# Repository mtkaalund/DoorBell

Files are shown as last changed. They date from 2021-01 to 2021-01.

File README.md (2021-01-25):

# DoorBell
Perhaps an over-engineered doorbell using a Arduino Pro Mini and a DFPlayer Mini.

## Hardware
The schematic are done in KiCad 5. 
A little story, at first I only meant to put a electrial schematic together, so it was easier to create a breadboard for this project.

But as I thought it would be a good pratics to create a pcb of it (mostly because it has been a long time since I did one).

As I was working with creating the schematics and the pcb, I tought it was underused, as it did'nt use all or expose the pins on the arduino or the DFPlayer Mini.
So I exposed them to the world and now it became a semi development board for the Arduino Pro Mini and DFPlayer Mini.

There are two headers "Arduino IO" and "DFPlayer IO" which expose the remaining IO's.

### DFPlayer IO
 Header Pin | DFPlayer Pin
------------|--------------
1 | DF Adkey 2
2 | DF Adkey 1
3 | DF IO 2
4 | DF IO 1
5 | DF DAC L
6 | DF DAC R

### Arduino IO
Header Pin | Arduino Pin 
-----------|-------------
1 | GND  
2 | VCC 
3 | A3   
4 | A2  
5 | A1  
6 | 13 ( SCK ) 
7 | 12 ( MISO )
8 | 9 ( Low battery LED )
9 | 8
10 | Reset
11 | 0 ( Rx )
12 | 1 ( Tx )
13 | GND
14 | VCC

### Libs
[Kicad footprints](https://github.com/joeylevy/KiCad_Arduino_Nano_DFPlayer_footprints)
[Kicad schematic symbols](https://github.com/RoboUlbricht/kicad.lib)

### Schematic
Can be found in the [hardware](https://github.com/mtkaalund/DoorBell/tree/main/hardware/DoorBell) folder as
either [Kicad Schematic](https://github.com/mtkaalund/DoorBell/blob/main/hardware/DoorBell/DoorBell.sch) or as a [PDF](https://github.com/mtkaalund/DoorBell/blob/main/hardware/DoorBell/DoorBell.pdf).

The pcb layout I have done can also be found as [Kicad PCB](https://github.com/mtkaalund/DoorBell/blob/main/hardware/DoorBell/DoorBell.kicad_pcb) or as pdf's [B_cu.pdf](https://github.com/mtkaalund/DoorBell/blob/main/hardware/DoorBell/DoorBell-B_Cu.pdf) [F_cu.pdf](https://github.com/mtkaalund/DoorBell/blob/main/hardware/DoorBell/DoorBell-F_Cu.pdf) [F_SilkS.pdf](https://github.com/mtkaalund/DoorBell/blob/main/hardware/DoorBell/DoorBell-F_SilkS.pdf)

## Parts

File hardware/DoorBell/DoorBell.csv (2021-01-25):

Id | Designator | Package | Quantity | Designation | Supplier and ref
1 | REF** | WEEE-Logo_4.2x6mm_SilkScreen | 1 | WEEE-Logo_4.2x6mm_SilkScreen
2 | REF** | OSHW-Logo2_7.3x6mm_SilkScreen | 1 | OSHW-Logo2_7.3x6mm_SilkScreen
3 | REF** | KiCad-Logo2_8mm_SilkScreen | 1 | KiCad-Logo2_8mm_SilkScreen
4 | P1 | Socket_Strip_Arduino_1x12 | 1 | Digital
5 | P2 | Socket_Strip_Arduino_1x06 | 1 | COM
6 | P3,P5 | Socket_Strip_Arduino_1x02 | 2 | ADC
7 | P4 | Socket_Strip_Arduino_1x12 | 1 | Analog
8 | C1 | C_Rect_L7.0mm_W2.5mm_P5.00mm | 1 | 100n
9 | D1 | D_DO-35_SOD27_P7.62mm_Horizontal | 1 | 1N4148
10 | D2 | LED_D3.0mm | 1 | LED
11 | J1 | BarrelJack_Horizontal | 1 | Barrel_Jack_Switch_Pin3Ring
12 | J2 | USB_A_CONNFLY_DS1095-WNR0 | 1 | USB_A
13 | J3 | PinHeader_1x02_P2.54mm_Vertical | 1 | Speaker
14 | J4 | PinHeader_1x14_P2.54mm_Vertical | 1 | ARDUINO_IO
15 | J5 | PinHeader_1x06_P2.54mm_Vertical | 1 | DFPlayerIO
16 | R1,R2,R3,R4,R5,R6,R9 | R_Axial_DIN0204_L3.6mm_D1.6mm_P7.62mm_Horizontal | 7 | 1K
17 | R7 | R_Axial_DIN0204_L3.6mm_D1.6mm_P7.62mm_Horizontal | 1 | 10K
18 | R8 | R_Axial_DIN0204_L3.6mm_D1.6mm_P7.62mm_Horizontal | 1 | 7K
19 | R10 | R_Axial_DIN0204_L3.6mm_D1.6mm_P7.62mm_Horizontal | 1 | 100
20 | SW1 | TerminalBlock_RND_205-00001_1x02_P5.00mm_Horizontal | 1 | DoorBell
21 | SW2 | TerminalBlock_RND_205-00001_1x02_P5.00mm_Horizontal | 1 | Volume Up
22 | SW3 | TerminalBlock_RND_205-00001_1x02_P5.00mm_Horizontal | 1 | Volume Down
23 | SW4 | TerminalBlock_RND_205-00001_1x02_P5.00mm_Horizontal | 1 | Select
24 | SW5 | TerminalBlock_RND_205-00001_1x02_P5.00mm_Horizontal | 1 | Next
25 | SW6 | TerminalBlock_RND_205-00001_1x02_P5.00mm_Horizontal | 1 | Prev
26 | U1 | DFPlayer_V2 | 1 | DFPLAYER_MINI
27 | H1,H2,H3,H4 | MountingHole_5.5mm_Pad_Via | 4 | MountingHole_Pad
28 | D3 | LED_D3.0mm | 1 | LowBatteryLED
29 | R11 | R_Axial_DIN0204_L3.6mm_D1.6mm_P7.62mm_Horizontal | 1 | 220

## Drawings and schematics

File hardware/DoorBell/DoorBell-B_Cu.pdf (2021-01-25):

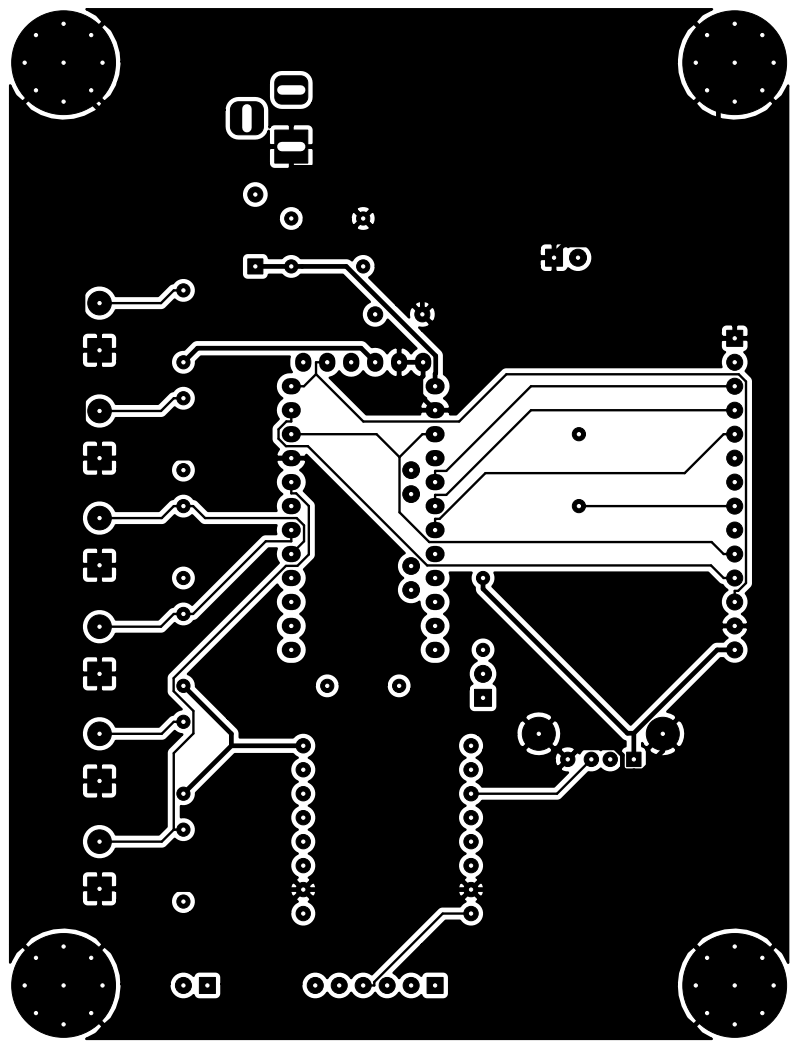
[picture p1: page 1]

File: DoorBell.kicad_pcb Sheet: mtkaalund.dk

Id: 1/1 Title: DoorBell Developmentboard

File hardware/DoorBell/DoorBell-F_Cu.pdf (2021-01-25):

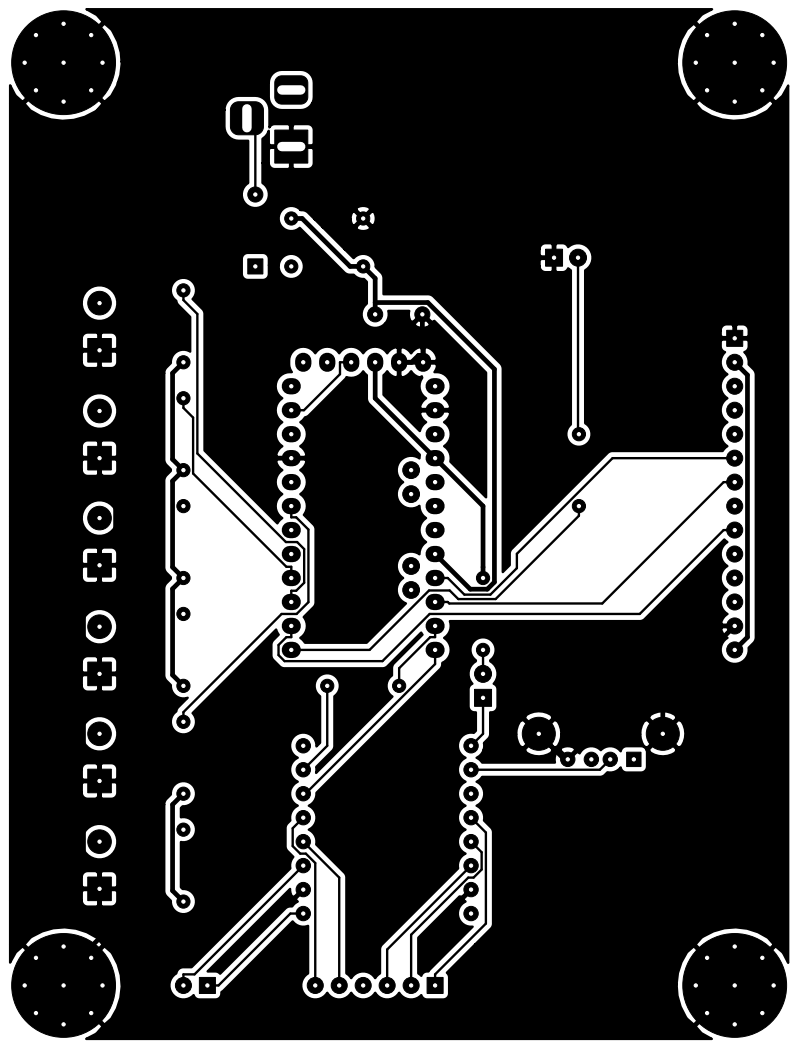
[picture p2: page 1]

File: DoorBell.kicad_pcb Sheet: mtkaalund.dk

Id: 1/1 Title: DoorBell Developmentboard

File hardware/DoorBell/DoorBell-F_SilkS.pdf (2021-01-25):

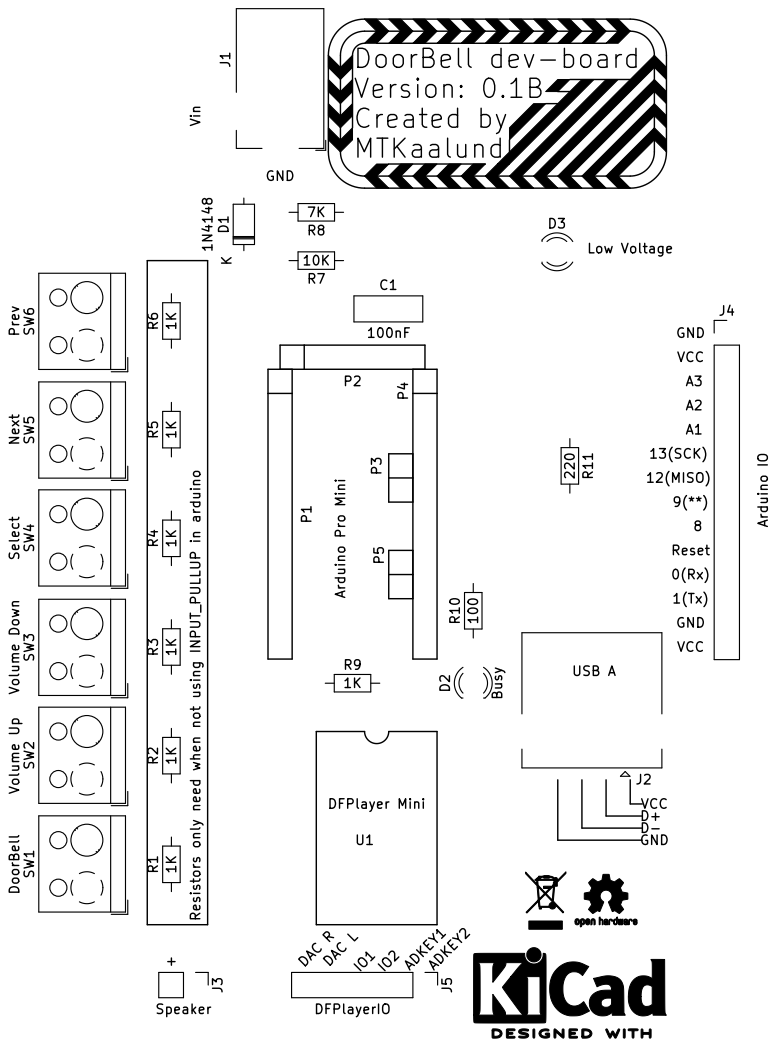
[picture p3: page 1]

File: DoorBell.kicad_pcb Sheet: mtkaalund.dk DoorBell dev-board
Version: 0.1B
Created by

Id: 1/1 Title: DoorBell Developmentboard

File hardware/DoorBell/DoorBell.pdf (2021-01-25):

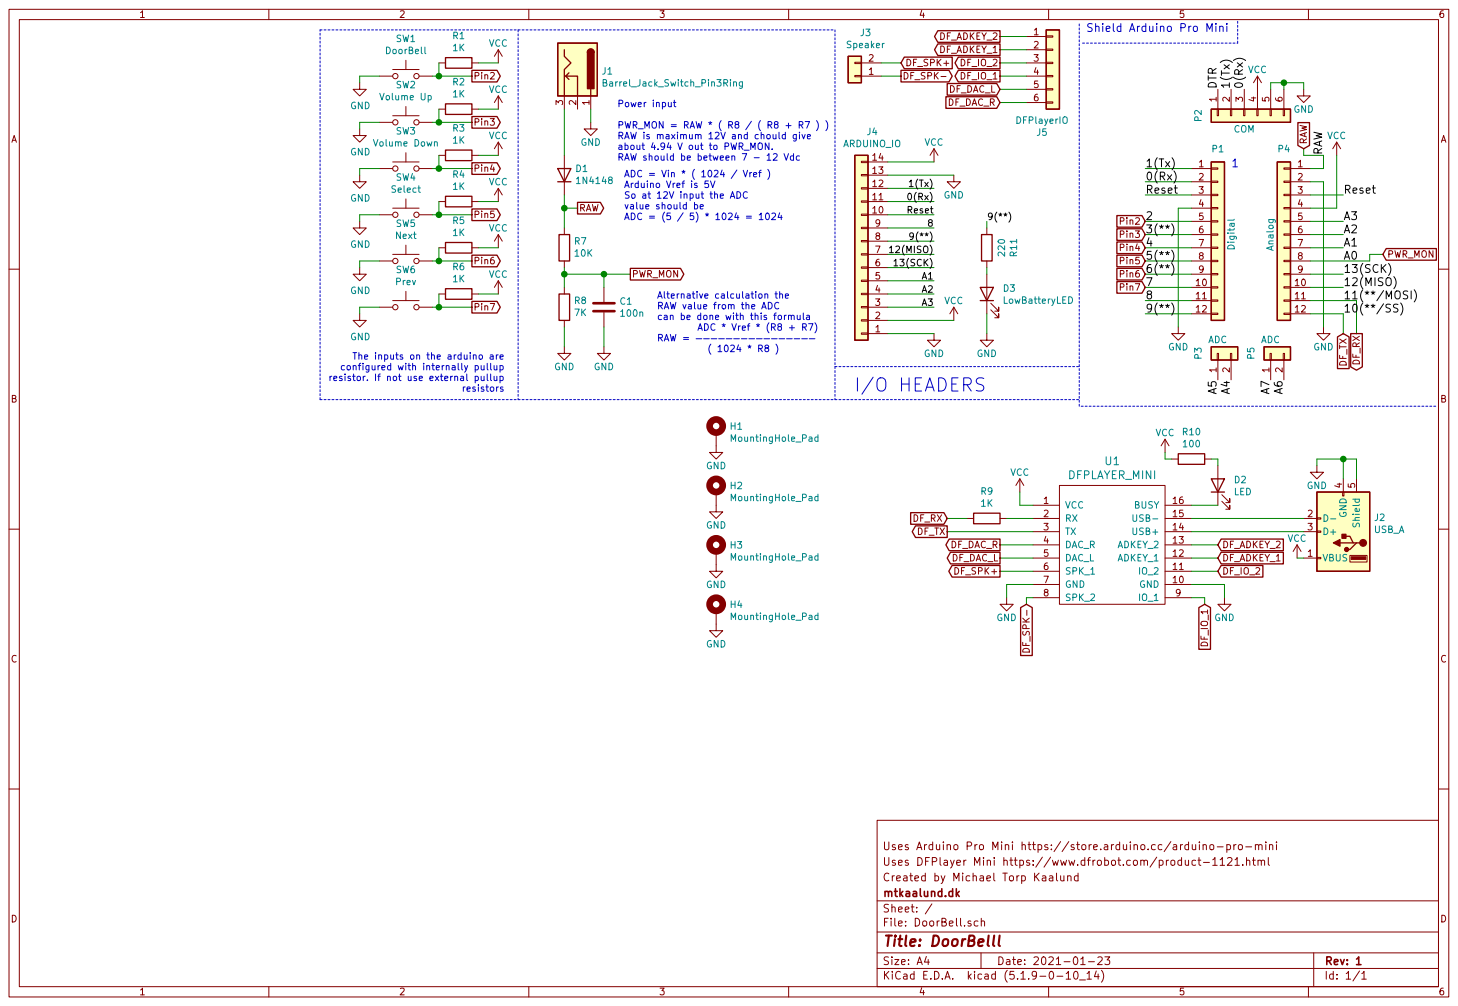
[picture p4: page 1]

1K GND GND GND GND

RAW is maximum 12V and chould give about 4.94 V out to PWR_MON. RAW should be between 7 - 12 Vdc The inputs on the arduino are

ADC = Vin * ( 1024 / Vref ) Arduino Vref is 5V

So at 12V input the ADC value should be ADC = (5 / 5) * 1024 = 1024

LowBatteryLED 220 R11 GND GND GND GND

can be done with this formula
ADC * Vref * (R8 + R7) RAW =

Uses Arduino Pro Mini https://store.arduino.cc/arduino-pro-mini GND
I/O HEADERS

configured with internally pullup
resistor. If not use external pullup

Uses DFPlayer Mini https://www.dfrobot.com/product-1121.html
Id: 1/1 Title: DoorBelll File: DoorBell.sch Sheet: / mtkaalund.dk Created by Michael Torp Kaalund

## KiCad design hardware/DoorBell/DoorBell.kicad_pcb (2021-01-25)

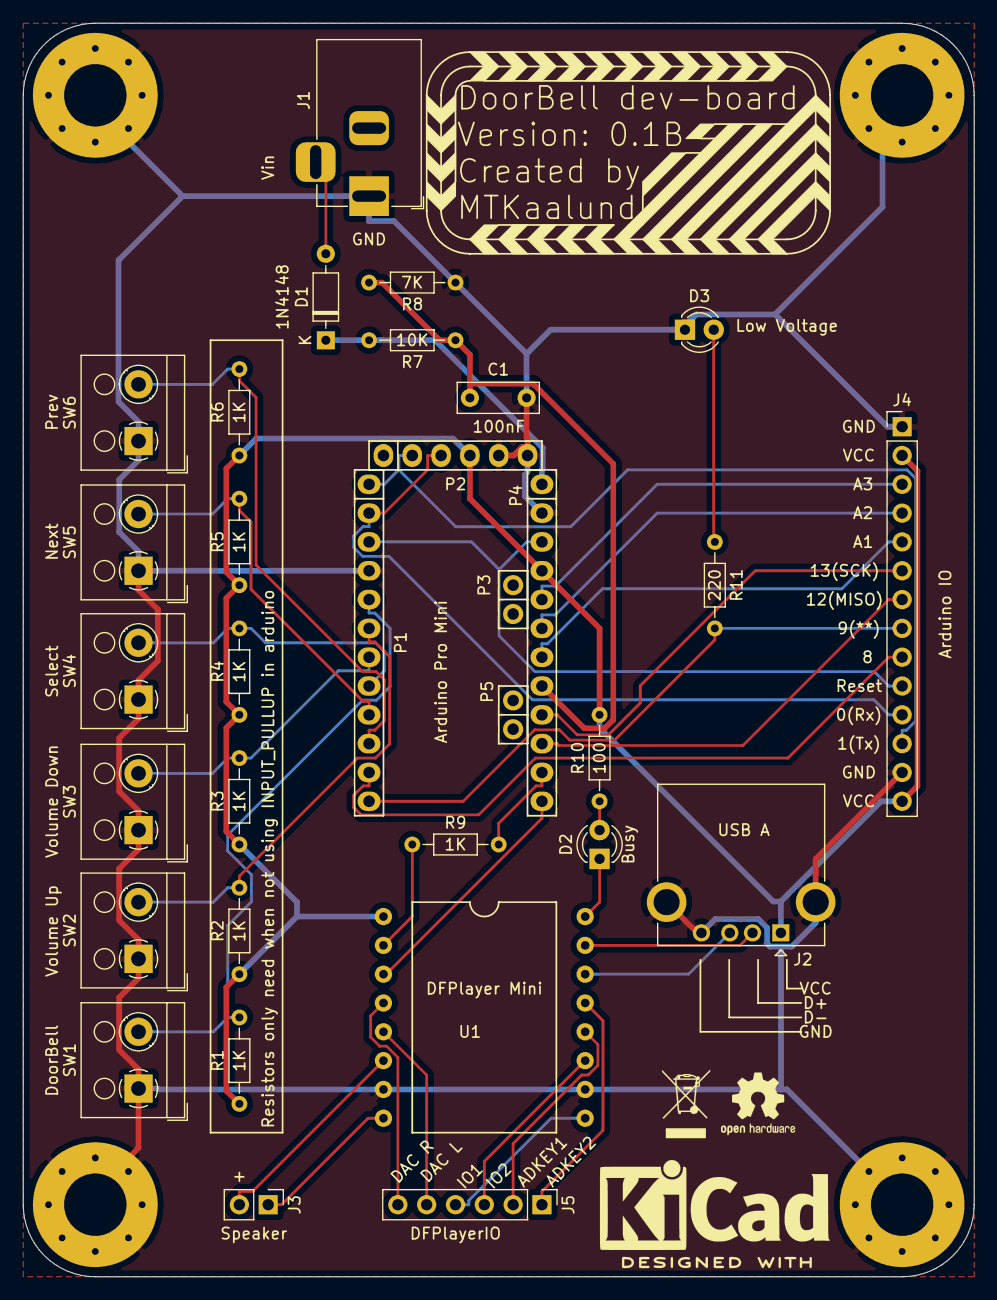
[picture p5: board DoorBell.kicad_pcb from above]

Board: 2 copper layers, 83.8 x 110.5 mm, 39 parts (0 on the bottom side), 37 nets.

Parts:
C1: 100n; C_Rect_L7.0mm_W2.5mm_P5.00mm
D1: 1N4148; D_DO-35_SOD27_P7.62mm_Horizontal
D2: LED; LED_D3.0mm
D3: LowBatteryLED; LED_D3.0mm
H1, H2, H3, H4: MountingHole_Pad; MountingHole_5.5mm_Pad_Via
J1: Barrel_Jack_Switch_Pin3Ring; BarrelJack_Horizontal
J2: USB_A; USB_A_CONNFLY_DS1095-WNR0
J3: Speaker; PinHeader_1x02_P2.54mm_Vertical
J4: ARDUINO_IO; PinHeader_1x14_P2.54mm_Vertical
J5: DFPlayerIO; PinHeader_1x06_P2.54mm_Vertical
LOGO1: KiCad-Logo2_8mm_SilkScreen
LOGO2: WEEE-Logo_4.2x6mm_SilkScreen
LOGO3: OSHW-Logo2_7.3x6mm_SilkScreen
P1: Digital; Socket_Strip_Arduino_1x12
P2: COM; Socket_Strip_Arduino_1x06
P3, P5: ADC; Socket_Strip_Arduino_1x02
P4: Analog; Socket_Strip_Arduino_1x12
R1, R2, R3, R4, R5, R6, R9: 1K; R_Axial_DIN0204_L3.6mm_D1.6mm_P7.62mm_Horizontal
R7: 10K; R_Axial_DIN0204_L3.6mm_D1.6mm_P7.62mm_Horizontal
R8: 7K; R_Axial_DIN0204_L3.6mm_D1.6mm_P7.62mm_Horizontal
R10: 100; R_Axial_DIN0204_L3.6mm_D1.6mm_P7.62mm_Horizontal
R11: 220; R_Axial_DIN0204_L3.6mm_D1.6mm_P7.62mm_Horizontal
SW1: DoorBell; TerminalBlock_RND_205-00001_1x02_P5.00mm_Horizontal
SW2: Volume Up; TerminalBlock_RND_205-00001_1x02_P5.00mm_Horizontal
SW3: Volume Down; TerminalBlock_RND_205-00001_1x02_P5.00mm_Horizontal
SW4: Select; TerminalBlock_RND_205-00001_1x02_P5.00mm_Horizontal
SW5: Next; TerminalBlock_RND_205-00001_1x02_P5.00mm_Horizontal
SW6: Prev; TerminalBlock_RND_205-00001_1x02_P5.00mm_Horizontal
U1: DFPLAYER_MINI; DFPlayer_V2

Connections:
/0(Rx): J4.11, P1.2, P2.3
/1(Tx): J4.12, P1.1, P2.2
/8: J4.9, P1.11
/9(**): J4.8, P1.12, R11.2
/12(MISO): J4.7, P4.10
/13(SCK): J4.6, P4.9
/A1: J4.5, P4.7
/A2: J4.4, P4.6
/A3: J4.3, P4.5
/Reset: J4.10, P1.3, P4.3
DF_ADKEY_1: J5.2, U1.12
DF_ADKEY_2: J5.1, U1.13
DF_DAC_L: J5.5, U1.5
DF_DAC_R: J5.6, U1.4
DF_IO_1: J5.4, U1.9
DF_IO_2: J5.3, U1.11
DF_RX: P4.11, R9.2
DF_SPK+: J3.2, U1.6
DF_SPK-: J3.1, U1.8
DF_TX: P4.12, U1.3
GND: C1.2, D3.1, H1.1, H2.1, H3.1, H4.1, J1.1, J2.4, J2.5, J4.1, J4.13, P1.4, P2.5, P2.6, P4.2, R8.1, SW1.1, SW2.1, SW3.1, SW4.1, SW5.1, SW6.1, U1.7, U1.10
unnamed: D1.2, J1.3
unnamed: D2.1, U1.16
unnamed: D2.2, R10.1
unnamed: D3.2, R11.1
unnamed: J2.2, U1.15
unnamed: J2.3, U1.14
unnamed: R9.1, U1.2
PWR_MON: C1.1, P4.8, R7.1, R8.2
Pin2: P1.5, R1.2, SW1.2
Pin3: P1.6, R2.2, SW2.2
Pin4: P1.7, R3.2, SW3.2
Pin5: P1.8, R4.2, SW4.2
Pin6: P1.9, R5.2, SW5.2
Pin7: P1.10, R6.2, SW6.2
RAW: D1.1, P4.1, R7.2
VCC: J2.1, J4.2, J4.14, P2.4, P4.4, R1.1, R2.1, R3.1, R4.1, R5.1, R6.1, R10.2, U1.1

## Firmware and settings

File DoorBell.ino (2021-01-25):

// Author: Michael Torp Kaalund 
// File: DoorBell.ino
// Description:
//  An over engineered doorbell solution using the DFPlayerMini board.
//  It has following buttons connected to the arduino pro mini as follows:
//    Doorbell    - pin 2
//    Volume up   - pin 3
//    Volume down - pin 4
//    Select      - pin 5
//    Next sound  - pin 6
//    Prev sound  - pin 7
// In order to compile you'll need the arduino enviroment and ezButton lib and DFRobotDFPlayerMini lib.
// https://arduinogetstarted.com/library/arduino-multiple-button-all-example
// https://wiki.dfrobot.com/DFPlayer_Mini_SKU_DFR0299

#include <Arduino.h>
#include <EEPROM.h>
#include <SoftwareSerial.h>
#include <DFRobotDFPlayerMini.h>
#include <ezButton.h>

#include "SerialPrintMessages.h"

  // Buttons ( using C++ enum class )
enum class button {
  DOORBELL,
  VOL_PLUS,
  VOL_MINUS,
  SELECT,
  NEXT,
  PREV,
  END
};

ezButton *buttons[ (int) button::END ] = {
  new ezButton(2),
  new ezButton(3),
  new ezButton(4),
  new ezButton(5),
  new ezButton(6),
  new ezButton(7)
};

typedef struct
{
  int saved_number;
  int volume;
} stats;

static stats ee_stats;
const int state_eeprom_address = 0;

static int max_files = 0;

// Our power monitor input pin
const int pwr_mon_pin = A0;
const int low_voltage_pin = 9;
#define VDIV_R8       7000    // Value of R8 in the resistor divider network
#define VDIV_R7      10000    // Value of R7 in the resistor divider network
#define VREF             5    // Arduino reference voltage
#define PWR_IN(x) ( ( (float) (x) * VREF * ( VDIV_R8 + VDIV_R7 ) ) / ( 1024 * VDIV_R8 ) )
#define CALC_ADC(x) ( (x) * 1024 * ((VDIV_R8) / ( VDIV_R8 + VDIV_R7 ) ) / VREF )
#define VOLTAGE_MIN CALC_ADC( 8.3 ) 
const int read_adc_every = 50; // Reading the ADC every 500 ms
const int read_adc_number = 10; // the number of times adc is going to be readed
int adc_reading[ read_adc_number ];
int adc_count = 0;
static int adc_timer = 0;
int adc_total = 0;
int adc_value = 0;
bool low_voltage_is_active = false;
static uint8_t low_voltage_counter = 0;


// Setting for the DFPlayer Mini
SoftwareSerial dfplayer_serial( 10, 11 ); // RX, TX
DFRobotDFPlayerMini cDFPlayer;

void setup() {
  // Read EEPROM
  EEPROM.get( state_eeprom_address, ee_stats );
  
  dfplayer_serial.begin( 9600 );
  Serial.begin( 115200 );

  mtk::PrintWelcome();

  if( ! cDFPlayer.begin( dfplayer_serial ) ) 
  {
    mtk::PrintDFPlayerFailedToInit();
  }
  Serial.println(F("READY!"));

  // Reading the current maks count off files
  max_files = cDFPlayer.readFileCounts();
  // The saved filenumber is bigger that the
  // maximum availeble files. Then set it to the maximum
  if( ee_stats.saved_number > max_files ) 
    ee_stats.saved_number = max_files;

  if( ee_stats.saved_number < 0 )
    ee_stats.saved_number = 0;

  if( ee_stats.volume > 30 )
    ee_stats.volume = 30;

  if( ee_stats.volume < 0 )
    ee_stats.volume = 0;

  cDFPlayer.volume( ee_stats.volume );
  cDFPlayer.disableLoop();
  cDFPlayer.play( ee_stats.saved_number );

  Serial.print("Found : ");
  Serial.print( max_files );
  Serial.println(" files on the sd card");
  Serial.print("Saved number: ");
  Serial.print((int)ee_stats.saved_number);
  Serial.print(" Volume: ");
  Serial.println((int)ee_stats.volume);

  adc_timer = millis();
  // Resets to adc_reading's to 0
  for( int i = 0; i < read_adc_number; i++ )
  {
    adc_reading[ i ] = 0;
  }
}

void loop() {
  // First reading the buttons
  for( int i = 0; i < (int)button::END; i++ )
  {
     buttons[ i ]->loop();
  }

  // We are going to read the adc at an interval atleast read_adc_every
  if( (millis() - adc_timer ) > read_adc_every )
  {
    adc_timer = millis();
    // We are going to smooth out the adc over read_adc_number times. 
    adc_total -= adc_reading[ adc_count ];
    adc_reading[ adc_count ] = analogRead( pwr_mon_pin );
    total += adc_reading[ adc_count ];
    adc_count++;
    // Wrap adc_count around
    if( adc_count >= read_adc_number )
    {
      adc_count = 0;
    }
    // Calculate the average
    adc_value = adc_total / read_adc_number;

    Serial.print( "Power voltage: ");
    Serial.print( PWR_IN( adc_value ) );
    Serial.println(" V");

    // If the read value is equal or lower than VOLTAGE_MIN
    // the set low_voltage_is_active to true
    // and low_voltage_pin to output
    if( adc_value <= VOLTAGE_MIN )
    {
      Serial.println("Low voltage");
      low_voltage_is_active = true;

      pinMode(low_voltage_pin, OUTPUT);
      // TODO: Alert user 
    }

    // Here if the adc_value is more than the VOLTAGE_MIN and low_voltage_is_active is true
    // then we are going to low_voltage_pin to input and low_voltage_is_active to false
    if( adc_value > VOLTAGE_MIN && low_voltage_is_active == true)
    {
      pinMode(low_voltage_pin, INPUT);
      low_voltage_is_active = false;
    }

    // if low_voltage_is_active then we will use
    // low_voltage_counter to fade in out
    if( low_voltage_is_active == true )
    {
      low_voltage_counter += 5;
      if( low_voltage_counter > 255 )
      {
        low_voltage_counter = 10;
      }
      analogWrite( low_voltage_pin, low_voltage_counter );
    }
  }

  if( buttons[ (int) button::DOORBELL ]->isPressed() )  
  {
    Serial.println("DOORBELL pressed");
    cDFPlayer.play( (int) ee_stats.saved_number ); 
  }

  if( buttons[ (int) button::VOL_PLUS ]->isPressed() )
  {
    Serial.print("VOL_PLUS pressed : ");
    if( ee_stats.volume < 30 )
    {
      cDFPlayer.volumeUp();
      ee_stats.volume++;      
    }
    Serial.println((int)ee_stats.volume);
  }

  if( buttons[ (int) button::VOL_MINUS ]->isPressed() )
  {
    Serial.print("VOL_MINUS pressed : ");
    if( ee_stats.volume > 0 ) {
      cDFPlayer.volumeDown();
      ee_stats.volume--;
    }
    Serial.println((int)ee_stats.volume);
  }

  if( buttons[ (int) button::SELECT ]->isPressed() )
  {
    Serial.println("SELECT pressed");
    // Here we are going to save ee_stats to EEPROM
    EEPROM.put( state_eeprom_address, ee_stats );
  }
  
  if( buttons[ (int) button::NEXT ]->isPressed() )
  {
    Serial.print("NEXT pressed : ");
    if( ee_stats.saved_number < max_files ) 
    {
      ee_stats.saved_number++;
      cDFPlayer.play( (int) ee_stats.saved_number );
    }
    Serial.println( (int) ee_stats.saved_number );
  }

  if( buttons[ (int) button::PREV ]->isPressed() )
  {
    Serial.println("PREV pressed : ");
    if( ee_stats.saved_number > 0 ) 
    {
      ee_stats.saved_number--;
      cDFPlayer.play( (int) ee_stats.saved_number );
    }
    Serial.println( (int) ee_stats.saved_number );
  }

  if( cDFPlayer.available() ) {
    mtk::DFPlayerPrintStatus( cDFPlayer.readType(), cDFPlayer.read() ); // Print the detail message from DFPlayer
  }
}

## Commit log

2021-01-23 Adding hardware schematic
    [DoorBell.kicad_pcb, DoorBell.sch]
2021-01-23 Finished for now the power input circuit
    [DoorBell.sch]
2021-01-23 Adding notes to pwr
    [DoorBell.sch]
2021-01-23 Updated page layout
    [DoorBell.sch]
2021-01-23 Almost finish with v1 of the schematic
    [DoorBell.sch]
2021-01-23 Pdf version of schematic
2021-01-23 First edition of low voltage
2021-01-24 Added mounting holes
    [DoorBell.kicad_pcb, DoorBell.sch]
2021-01-24 V1 of PCB finished
    [DoorBell.dsn]
2021-01-24 PDF version of PCB
2021-01-24 Updated PDF of schematics
2021-01-25 Added a low voltage led to the board on pin 9.
    [DoorBell.csv, DoorBell.dsn, DoorBell.kicad_pcb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]
2021-01-25 Schematic pdf updated
2021-01-25 First version of the low voltage code
2021-01-25 Updated silkscreen
    [DoorBell.kicad_pcb]
2021-01-25 Added dimensions
    [DoorBell.kicad_pcb]
2021-01-25 Adding adc smoothing to the code
